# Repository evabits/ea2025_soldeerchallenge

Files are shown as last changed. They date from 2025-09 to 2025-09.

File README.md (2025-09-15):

# ea2025_soldeerchallenge

Hardware and Software for the soldering challenge of the Electronics and Automation fair 2025. The board includes an RP2040, a 5x5 neopixel LED array and a breakout connector. You can use it as an RP2040 development kit afterwards, starting with the Arduino file. Leave a note on our linkedin-page on how you've done. Good luck soldering!

## Important Notice  

Some Arduino board libraries may cause **GPIO pattern mismatches**.  

The only supported and correct board for running `FHI_SolderChallenge2025.ino` is:  

**Raspberry Pi Pico (RP2040) by Earle F. Philhower**

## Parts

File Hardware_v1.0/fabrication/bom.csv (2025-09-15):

Value | References | Footprint | Partnumber | Quantity Per PCB | Description
10pf | C6 C9 | C_0402_1005Metric |  | 2
22pF | C12 C13 | C_0402_1005Metric |  | 2
0.1uF | C1 C2 C3 C4 C5 C7 C8 | C_0402_1005Metric |  | 7
1uF | C11 C14 C15 | C_0603_1608Metric |  | 3
WS2812B | D2 D3 D4 D5 D6 D7 D8 D9 D10 D11 D12 D13 D14 D15 D16 D17 D18 D19 D20 D21 D22 D23 D24 D25 D26 | LED_WS2812B_PLCC4_5.0x5.0mm_P3.2mm |  | 25 | RGB LED with integrated controller
Conn_02x16_Odd_Even | J3 | PinHeader_2x16_P2.54mm_Horizontal |  | 1 | Generic connector, double row, 02x16, odd/even pin numbering scheme (row 1 odd numbers, row 2 even numbers), script generated (kicad-library-utils/schlib/autogen/connector/)
USB4085-GF-A_REVB | J2 | GCT_USB4085-GF-A_REVB | USB4085-GF-A | 1
27R | R8 R9 | R_0603_1608Metric |  | 2
1k5 | R1 | R_0603_1608Metric |  | 1
5k1 | R5 R6 | R_0603_1608Metric |  | 2
10K | R3 | R_0603_1608Metric |  | 1
1M | R4 | R_0603_1608Metric |  | 1
SKRKAGE020 | SW1 | SW_Push_SPST_NO_Alps_SKRK | SKRKAGE020 | 1
74HCT1G125GW | U3 | SOT-353_SC-70-5 |  | 1
AP2112K-3.3V | U4 | TSOT-23-5 |  | 1
RP2040 | U1 | QFN-56-1EP_7x7mm_P0.4mm_EP3.1x3.1mm_ThermalVias |  | 1
W25Q128JVSIQ | U2 | SOIC-8_5.23x5.23mm_P1.27mm |  | 1
EVAbits_logo | V2 | EVAbits_newlogo 48x12mm | DNP | 1
QR-code | V1 | QRcode14mmx14mm | DNP | 1
evajig_logo | V3 | evajig_logo_40x10 | DNP | 1
12MHz,10pF | Y1 | Crystal_SMD_3225-4Pin_3.2x2.5mm | NX3225SA-12MHZ-STD-CSR-6 | 1

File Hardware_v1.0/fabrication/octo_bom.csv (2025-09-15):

Num | MPN | Qty | Schematic Reference | Description
0 | 22pF capacitor 0402 50V | 2 | C12 C13 | 22pF capacitor 0402 50V
1 | WS2812B | 25 | D2 D3 D4 D5 D6 D7 D8 D9 D10 D11 D12 D13 D14 D15 D16 D17 D18 D19 D20 D21 D22 D23 D24 D25 D26
2 | Conn_02x16_Odd_Even | 1 | J3
3 | USB4085-GF-A | 1 | J2
4 | SKRKAGE020 | 1 | SW1
5 | 74HCT1G125GW | 1 | U3
6 | AP2112K-3.3V | 1 | U4
7 | RP2040 | 1 | U1
8 | W25Q128JVSIQ | 1 | U2
9 | NX3225SA-12MHZ-STD-CSR-6 | 1 | Y1

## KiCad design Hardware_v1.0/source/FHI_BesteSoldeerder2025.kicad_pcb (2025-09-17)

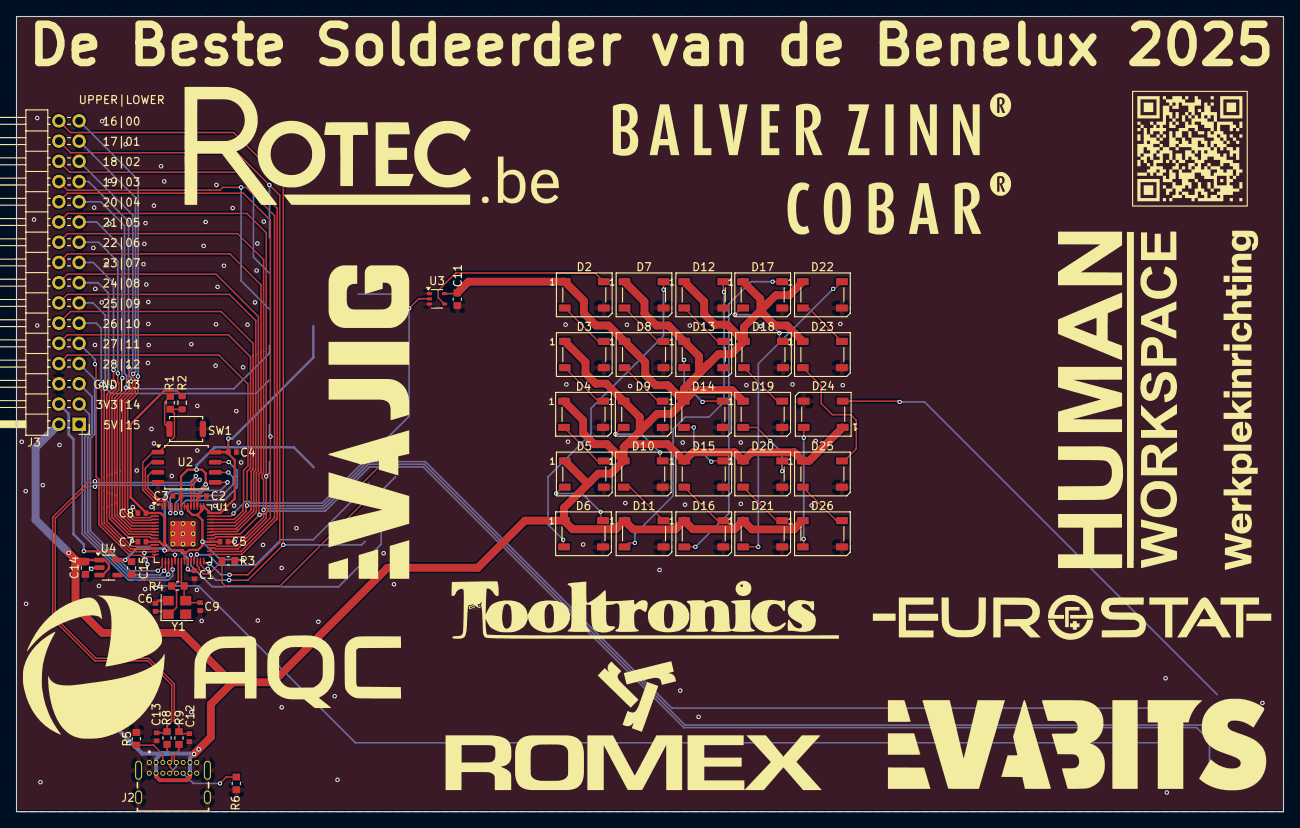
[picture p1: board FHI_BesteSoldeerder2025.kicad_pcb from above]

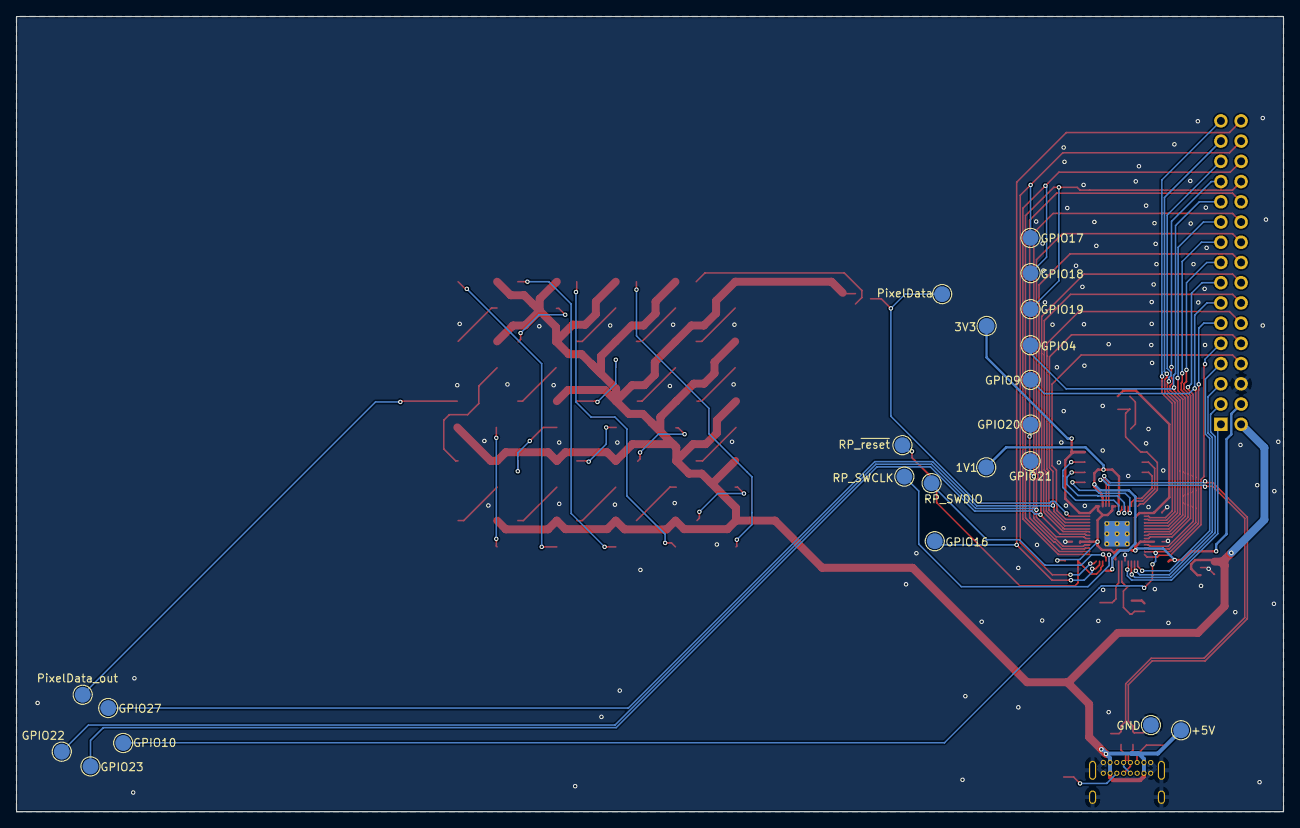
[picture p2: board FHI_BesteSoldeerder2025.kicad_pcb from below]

Board: 2 copper layers, 159.1 x 99.8 mm, 79 parts (21 on the bottom side), 78 nets.

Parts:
C1, C2, C3, C4, C5, C7, C8: 0.1uF; C_0402_1005Metric
C6, C9: 10pf; C_0402_1005Metric
C11, C14, C15: 1uF; C_0603_1608Metric
C12, C13: 22pF; C_0402_1005Metric
D2, D3, D4, D5, D6, D7, D8, D9, D10, D11, D12, D13, D14, D15, D16, D17, D18, D19, D20, D21, D22, D23, D24, D25, D26: WS2812B; LED_WS2812B_PLCC4_5.0x5.0mm_P3.2mm
J2: USB4085-GF-A_REVB; GCT_USB4085-GF-A_REVB
J3: Conn_02x16_Odd_Even; PinHeader_2x16_P2.54mm_Horizontal
R1: 1k5; R_0603_1608Metric
R2: DNP; R_0603_1608Metric
R3: 10K; R_0603_1608Metric
R4: 1M; R_0603_1608Metric
R5, R6: 5k1; R_0603_1608Metric
R8, R9: 27R; R_0603_1608Metric
SW1: SKRKAGE020; SW_Push_SPST_NO_Alps_SKRK
TP1: +5V; TestPoint_Pad_D1.5mm
TP3: GND; TestPoint_Pad_D1.5mm
TP28: GPIO27; TestPoint_Pad_D1.5mm
TP29: PixelData_out; TestPoint_Pad_D1.5mm
TP31: GPIO10; TestPoint_Pad_D1.5mm
TP32: GPIO22; TestPoint_Pad_D1.5mm
TP33: GPIO23; TestPoint_Pad_D1.5mm
TP55: GPIO21; TestPoint_Pad_D1.5mm
TP56: GPIO20; TestPoint_Pad_D1.5mm
TP57: GPIO9; TestPoint_Pad_D1.5mm
TP59: GPIO4; TestPoint_Pad_D1.5mm
TP60: GPIO19; TestPoint_Pad_D1.5mm
TP61: GPIO18; TestPoint_Pad_D1.5mm
TP62: GPIO17; TestPoint_Pad_D1.5mm
TP63: 1V1; TestPoint_Pad_D1.5mm
TP64: 3V3; TestPoint_Pad_D1.5mm
TP74: RP_SWDIO; TestPoint_Pad_D1.5mm
TP75: RP_~{reset}; TestPoint_Pad_D1.5mm
TP76: RP_SWCLK; TestPoint_Pad_D1.5mm
TP83: GPIO16; TestPoint_Pad_D1.5mm
TP84: PixelData; TestPoint_Pad_D1.5mm
U1: RP2040; QFN-56-1EP_7x7mm_P0.4mm_EP3.1x3.1mm_ThermalVias
U2: W25Q128JVSIQ; SOIC-8_5.23x5.23mm_P1.27mm
U3: 74HCT1G125GW; SOT-353_SC-70-5
U4: AP2112K-3.3V; TSOT-23-5
V1: QR-code; QRcode14mmx14mm
V2: EVAbits_logo; EVAbits_newlogo 48x12mm
V3: evajig_logo; evajig_logo_40x10
Y1: 12MHz,10pF; Crystal_SMD_3225-4Pin_3.2x2.5mm

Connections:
+3V3: C4.2, C5.2, C7.2, C8.2, C15.2, J3.4, R2.1, R3.2, TP64.1, U1.1 (IOVDD), U1.10 (IOVDD), U1.22 (IOVDD), U1.33 (IOVDD), U1.42 (IOVDD), U1.43 (ADC-AVDD), U1.44 (VREG-VIN), U1.48 (USB-VDD), U1.49 (IOVDD), U2.8 (VCC), U4.5 (OUT)
+5V: C11.2, C14.2, D2.1 (VDD), D3.1 (VDD), D4.1 (VDD), D5.1 (VDD), D6.1 (VDD), D7.1 (VDD), D8.1 (VDD), D9.1 (VDD), D10.1 (VDD), D11.1 (VDD), D12.1 (VDD), D13.1 (VDD), D14.1 (VDD), D15.1 (VDD), D16.1 (VDD), D17.1 (VDD), D18.1 (VDD), D19.1 (VDD), D20.1 (VDD), D21.1 (VDD), D22.1 (VDD), D23.1 (VDD), D24.1 (VDD), D25.1 (VDD), D26.1 (VDD), J2.A4 (VBUS), J2.A9 (VBUS), J2.B4 (VBUS), J2.B9 (VBUS), J3.2, TP1.1, U3.5 (Vcc), U4.1 (IN), U4.3 (EN)
/+1v1: C1.2, C2.2, C3.2, TP63.1, U1.23 (DVDD), U1.45 (VREG-VOUT), U1.50 (DVDD)
/GPIO00: J3.31, U1.2 (GPIO0)
/GPIO01: J3.29, U1.3 (GPIO1)
/GPIO02: J3.27, U1.4 (GPIO2)
/GPIO03: J3.25, U1.5 (GPIO3)
/GPIO04: J3.23, TP59.1, U1.6 (GPIO4)
/GPIO05: J3.21, U1.7 (GPIO5)
/GPIO06: J3.19, U1.8 (GPIO6)
/GPIO07: J3.17, U1.9 (GPIO7)
/GPIO08: J3.15, U1.11 (GPIO8)
/GPIO09: J3.13, TP57.1, U1.12 (GPIO9)
/GPIO10: J3.11, TP31.1, U1.13 (GPIO10)
/GPIO11: J3.9, U1.14 (GPIO11)
/GPIO12: J3.7, U1.15 (GPIO12)
/GPIO13: J3.5, U1.16 (GPIO13)
/GPIO14: J3.3, U1.17 (GPIO14)
/GPIO15: J3.1, U1.18 (GPIO15)
/GPIO16: J3.32, TP83.1, U1.27 (GPIO16)
/GPIO17: J3.30, TP62.1, U1.28 (GPIO17)
/GPIO18: J3.28, TP61.1, U1.29 (GPIO18)
/GPIO19: J3.26, TP60.1, U1.30 (GPIO19)
/GPIO20: J3.24, TP56.1, U1.31 (GPIO20)
/GPIO21: J3.22, TP55.1, U1.32 (GPIO21)
/GPIO22: J3.20, TP32.1, U1.34 (GPIO22)
/GPIO23: J3.18, TP33.1, U1.35 (GPIO23)
/GPIO24: J3.16, U1.36 (GPIO24)
/GPIO25: J3.14, U1.37 (GPIO25)
/GPIO26: J3.12, U1.38 (GPIO26/ADC0)
/GPIO27: J3.10, TP28.1, U1.39 (GPIO27/ADC1)
/GPIO28: J3.8, U1.40 (GPIO28/ADC2)
/NeoPixel_data: TP84.1, U1.41 (GPIO29/ADC3), U3.2 (A)
/NeoPixel_data_out: D24.2 (DOUT), TP29.1
/PICO_RESET: R3.1, TP75.1, U1.26 (RUN)
/PICO_TCKS: TP76.1, U1.24 (SWCLK)
/PICO_TMSS: TP74.1, U1.25 (SWDIO)
/QSPI_SCLK: U1.52 (QSPI-SCLK), U2.6 (CLK)
/QSPI_SD0: U1.53 (QSPI-SD0), U2.5 (DI(IO0))
/QSPI_SD1: U1.55 (QSPI-SD1), U2.2 (DO(IO1))
/QSPI_SD2: U1.54 (QSPI-SD2), U2.3 (IO2)
/QSPI_SD3: U1.51 (QSPI-SD3), U2.7 (IO3)
/QSPI_SS: R1.2, R2.2, U1.56 (QSPI-SS-N), U2.1 (~CS)
/USB_D+: C13.2, R8.1, U1.47 (USB-DP)
/USB_D-: C12.1, R9.1, U1.46 (USB-DM)
/USB_N: J2.A7 (DN1), J2.B7 (DN2), R9.2
/USB_P: J2.A6 (DP1), J2.B6 (DP2), R8.2
/~USB_BOOT: R1.1, SW1.2
GND: C1.1, C2.1, C3.1, C4.1, C5.1, C6.2, C7.1, C8.1, C9.1, C11.1, C12.2, C13.1, C14.1, C15.1, D2.3 (VSS), D3.3 (VSS), D4.3 (VSS), D5.3 (VSS), D6.3 (VSS), D7.3 (VSS), D8.3 (VSS), D9.3 (VSS), D10.3 (VSS), D11.3 (VSS), D12.3 (VSS), D13.3 (VSS), D14.3 (VSS), D15.3 (VSS), D16.3 (VSS), D17.3 (VSS), D18.3 (VSS), D19.3 (VSS), D20.3 (VSS), D21.3 (VSS), D22.3 (VSS), D23.3 (VSS), D24.3 (VSS), D25.3 (VSS), D26.3 (VSS), J2.A1 (GND), J2.A12 (GND), J2.B1 (GND), J2.B12 (GND), J2.S1 (SHELL), J2.S2 (SHELL), J2.S3 (SHELL), J2.S4 (SHELL), J3.6, R5.2, R6.2, SW1.1, TP3.1, U1.19 (TESTEN), U1.57 (GND), U2.4 (GND), U3.1 (~OE), U3.3 (GND), U4.2 (GND), Y1.2, Y1.4
unnamed: D2.4 (DIN), U3.4 (Y)
unnamed: D2.2 (DOUT), D3.4 (DIN)
unnamed: D3.2 (DOUT), D4.4 (DIN)
unnamed: D4.2 (DOUT), D5.4 (DIN)
unnamed: D5.2 (DOUT), D6.4 (DIN)
unnamed: D6.2 (DOUT), D7.4 (DIN)
unnamed: D7.2 (DOUT), D8.4 (DIN)
unnamed: D8.2 (DOUT), D9.4 (DIN)
unnamed: D9.2 (DOUT), D10.4 (DIN)
unnamed: D10.2 (DOUT), D11.4 (DIN)
unnamed: D11.2 (DOUT), D12.4 (DIN)
unnamed: D12.2 (DOUT), D13.4 (DIN)
unnamed: D13.2 (DOUT), D14.4 (DIN)
unnamed: D14.2 (DOUT), D15.4 (DIN)
unnamed: D15.2 (DOUT), D16.4 (DIN)
unnamed: D16.2 (DOUT), D17.4 (DIN)
unnamed: D17.2 (DOUT), D18.4 (DIN)
unnamed: D18.2 (DOUT), D19.4 (DIN)
unnamed: D19.2 (DOUT), D20.4 (DIN)
unnamed: D20.2 (DOUT), D21.4 (DIN)
unnamed: D21.2 (DOUT), D22.4 (DIN)
unnamed: D22.2 (DOUT), D23.4 (DIN)
unnamed: D23.2 (DOUT), D25.4 (DIN)
unnamed: D24.4 (DIN), D26.2 (DOUT)
unnamed: D25.2 (DOUT), D26.4 (DIN)
unnamed: J2.A5 (CC1), R5.1
unnamed: J2.B5 (CC2), R6.1
unnamed: C6.1, R4.2, U1.20 (XIN), Y1.1
unnamed: C9.2, R4.1, U1.21 (XOUT), Y1.3

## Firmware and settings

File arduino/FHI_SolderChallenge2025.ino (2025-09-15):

/// @file    Blink.ino
/// @brief   Blink the first LED of an LED strip
/// @example Blink.ino

// install the library to use FastLED.h
// https://docs.arduino.cc/libraries/fastled/
#include <FastLED.h>

// How many leds in your strip?
#define NUM_LEDS 25

#define LETTER_SPACING 0

#define NUM_PINS 28
// For led chips like WS2812, which have a data line, ground, and power, you just
// need to define DATA_PIN.  For led chipsets that are SPI based (four wires - data, clock,
// ground, and power), like the LPD8806 define both DATA_PIN and CLOCK_PIN
// Clock pin only needed for SPI based chipsets when not using hardware SPI
#define DATA_PIN 29
#define CLOCK_PIN 13

// Define the array of leds
CRGB leds[NUM_LEDS];

// Checkmark pattern
int checkmark[] = { 3, 9, 13, 17, 21 };
int checkmarkSize = sizeof(checkmark) / sizeof(checkmark[0]);

// Cross pattern
int cross[] = { 0, 6, 12, 18, 23, 20, 16, 8, 4 };
int crossSize = sizeof(cross) / sizeof(cross[0]);

// Pointer to faulty led
int pointer[] = { 2, 7, 12, 17, 11, 13 };
int pointerSize = sizeof(pointer) / sizeof(pointer[0]);

// Snake sequence
int snakeOrder[] = { 0, 5, 10, 15, 20, 21, 16, 11, 6, 1, 2, 7, 12, 17, 24, 22, 18, 13, 8, 3, 4, 9, 14, 19, 23 };
int snakeSize = sizeof(snakeOrder) / sizeof(snakeOrder[0]);

#define NUM_ROWS 5
#define NUM_COLS 5


// Array for each symbol  
const byte FONT_5x5[][NUM_ROWS] = {

  /* 'P' */ {
    0b11100,
    0b10010,
    0b11100,
    0b10000,
    0b10000
    },

  /* 'A' */ {
    0b01000,
    0b10100,
    0b11100,
    0b10100,
    0b10100
    },

  /* 'S' */ {
    0b01100,
    0b10000,
    0b01000,
    0b00100,
    0b11000},

  /* ! */ {
    0b10000,
    0b10000,
    0b10000,
    0b00000,
    0b10000
    }, 

  /* 'F' */ {
    0b11100,
    0b10000,
    0b11000,
    0b10000,
    0b10000
    },

  /* I */ {
    0b11100,
    0b01000,
    0b01000,
    0b01000,
    0b11100
    }, 

  /* L */ {
    0b10000,
    0b10000,
    0b10000,
    0b10000,
    0b11110
    }, 

  /* ' ' */ {
    0b00000,
    0b00000,
    0b00000,
    0b00000,
    0b00000
    }, // space
};

 
// LED map for letter scrolling
const uint8_t LED_MAP[NUM_ROWS][NUM_COLS] = {
  { 0,  5, 10, 15, 20 },
  { 1,  6, 11, 16, 21 },
  { 2,  7, 12, 17, 24 },
  { 3,  8, 13, 18, 22 },
  { 4,  9, 14, 19, 23 }
};

// store patterns
int fontIndexFromChar(char c) {
  switch (c) {
    case 'P': return 0;
    case 'A': return 1;
    case 'S': return 2;
    case '!': return 3;
    case 'F': return 4;
    case 'I': return 5;
    case 'L': return 6;
    case ' ': return 7;
    default:  return 7; // unknown -> space
  }
}

// matrix coordinates
inline int indexFromRowCol(int row, int col) {
  return LED_MAP[row][col];
}


//GPIO pins
int gpioPins[29] = {
  0, 1, 2, 3, 4, 5, 6, 7,
  8, 9, 10, 11, 12, 13, 14, 15,
  16, 17, 18, 19, 20, 21, 22, 23,
  24, 25, 26, 27, 28
};



// draw a single character column-by-column onto the 5x5 at a given global column
void drawTextColumnAt(int visCol, int globalCol, const char* text, CRGB color) {
  if (visCol < 0 || visCol >= NUM_COLS) return;

  // each character is NUM_COLS wide + 1 blank column spacing
  const int charWidth = NUM_COLS;
  const int spacing   = LETTER_SPACING;
  const int stride    = charWidth + spacing;

  if (globalCol < 0) return;

  // which character & which column inside that character?
  int charIdx     = globalCol / stride;
  int colInChar   = globalCol % stride;

  // outside the input string?
  int textLen = strlen(text);
  if (charIdx >= textLen) return;

  // spacing column?
  if (colInChar >= charWidth) return;

  // fetch the character's 5 row bitmap
  char c = toupper(text[charIdx]);
  int fi = fontIndexFromChar(c);

  // Copy pixels for this visible column
  for (int row = 0; row < NUM_ROWS; row++) {
    bool on = ((FONT_5x5[fi][row] >> (NUM_COLS - 1 - colInChar)) & 0x01);
     int idx = indexFromRowCol(row, visCol);
    if (idx >= 0 && idx < NUM_LEDS) {
      leds[idx] = on ? color : CRGB::Black;
    }
  }
}

// scroll the text 
void scrollText(const char* text, uint16_t stepDelayMs, CRGB color) {
  // total columns in the virtual text
  const int charWidth = NUM_COLS;
  const int spacing   = LETTER_SPACING;
  const int stride    = charWidth + spacing;
  int textCols = strlen(text) * stride;

  // sweep from off-screen right to off-screen left
  for (int offset = NUM_COLS; offset >= -textCols; offset--) {
    // Clear frame
    for (int i = 0; i < NUM_LEDS; i++) leds[i] = CRGB::Black;

    // render visible window columns
    for (int visCol = 0; visCol < NUM_COLS; visCol++) {
      int globalCol = visCol - offset; // which text column appears in this window column?
      drawTextColumnAt(visCol, globalCol, text, color);
    }

    FastLED.show();
    delay(stepDelayMs);
  }
}


void setup() {
  Serial.begin(115200);

  // Initialize pins
  for (int i = 0; i < 28; i++) {
    pinMode(gpioPins[i], OUTPUT);
  }

  // Uncomment/edit one of the following lines for your leds arrangement.
  // ## Clockless types ##
  FastLED.addLeds<NEOPIXEL, DATA_PIN>(leds, NUM_LEDS);  // GRB ordering is assumed

  

  // FastLED.addLeds<SM16703, DATA_PIN, RGB>(leds, NUM_LEDS);
  // FastLED.addLeds<TM1829, DATA_PIN, RGB>(leds, NUM_LEDS);
  // FastLED.addLeds<TM1812, DATA_PIN, RGB>(leds, NUM_LEDS);
  // FastLED.addLeds<TM1809, DATA_PIN, RGB>(leds, NUM_LEDS);
  // FastLED.addLeds<TM1804, DATA_PIN, RGB>(leds, NUM_LEDS);
  // FastLED.addLeds<TM1803, DATA_PIN, RGB>(leds, NUM_LEDS);
  // FastLED.addLeds<UCS1903, DATA_PIN, RGB>(leds, NUM_LEDS);
  // FastLED.addLeds<UCS1903B, DATA_PIN, RGB>(leds, NUM_LEDS);
  // FastLED.addLeds<UCS1904, DATA_PIN, RGB>(leds, NUM_LEDS);
  // FastLED.addLeds<UCS2903, DATA_PIN, RGB>(leds, NUM_LEDS);
  // FastLED.addLeds<WS2812, DATA_PIN, RGB>(leds, NUM_LEDS);  // GRB ordering is typical
  // FastLED.addLeds<WS2852, DATA_PIN, RGB>(leds, NUM_LEDS);  // GRB ordering is typical
  // FastLED.addLeds<WS2812B, DATA_PIN, RGB>(leds, NUM_LEDS);  // GRB ordering is typical
  // FastLED.addLeds<GS1903, DATA_PIN, RGB>(leds, NUM_LEDS);
  // FastLED.addLeds<SK6812, DATA_PIN, RGB>(leds, NUM_LEDS);  // GRB ordering is typical
  // FastLED.addLeds<SK6822, DATA_PIN, RGB>(leds, NUM_LEDS);
  // FastLED.addLeds<APA106, DATA_PIN, RGB>(leds, NUM_LEDS);
  // FastLED.addLeds<PL9823, DATA_PIN, RGB>(leds, NUM_LEDS);
  // FastLED.addLeds<SK6822, DATA_PIN, RGB>(leds, NUM_LEDS);
  // FastLED.addLeds<WS2811, DATA_PIN, RGB>(leds, NUM_LEDS);
  // FastLED.addLeds<WS2813, DATA_PIN, RGB>(leds, NUM_LEDS);
  // FastLED.addLeds<APA104, DATA_PIN, RGB>(leds, NUM_LEDS);
  // FastLED.addLeds<WS2811_400, DATA_PIN, RGB>(leds, NUM_LEDS);
  // FastLED.addLeds<GE8822, DATA_PIN, RGB>(leds, NUM_LEDS);
  // FastLED.addLeds<GW6205, DATA_PIN, RGB>(leds, NUM_LEDS);
  // FastLED.addLeds<GW6205_400, DATA_PIN, RGB>(leds, NUM_LEDS);
  // FastLED.addLeds<LPD1886, DATA_PIN, RGB>(leds, NUM_LEDS);
  // FastLED.addLeds<LPD1886_8BIT, DATA_PIN, RGB>(leds, NUM_LEDS);
  // ## Clocked (SPI) types ##
  // FastLED.addLeds<LPD6803, DATA_PIN, CLOCK_PIN, RGB>(leds, NUM_LEDS);  // GRB ordering is typical
  // FastLED.addLeds<LPD8806, DATA_PIN, CLOCK_PIN, RGB>(leds, NUM_LEDS);  // GRB ordering is typical
  // FastLED.addLeds<WS2801, DATA_PIN, CLOCK_PIN, RGB>(leds, NUM_LEDS);
  // FastLED.addLeds<WS2803, DATA_PIN, CLOCK_PIN, RGB>(leds, NUM_LEDS);
  // FastLED.addLeds<SM16716, DATA_PIN, CLOCK_PIN, RGB>(leds, NUM_LEDS);
  // FastLED.addLeds<P9813, DATA_PIN, CLOCK_PIN, RGB>(leds, NUM_LEDS);  // BGR ordering is typical
  // FastLED.addLeds<DOTSTAR, DATA_PIN, CLOCK_PIN, RGB>(leds, NUM_LEDS);  // BGR ordering is typical
  // FastLED.addLeds<APA102, DATA_PIN, CLOCK_PIN, RGB>(leds, NUM_LEDS);  // BGR ordering is typical
  // FastLED.addLeds<SK9822, DATA_PIN, CLOCK_PIN, RGB>(leds, NUM_LEDS);  // BGR ordering is typical
  FastLED.setBrightness(3);

  // for (int dot = 0; dot < NUM_LEDS; dot++) {

  //   for (int Hue = 0; Hue < 255; dot++) {
  //     Hue = Hue + 10;
  //     if (Hue == 0) {
  //       Hue = 10;
  //     }
  //     leds[dot] = CHSV(Hue, 255, 255);
  //     FastLED.show();
  //   }
  // }

  Serial.println("Ready: Type commands (p1, p2, ok, cross)");
}




void loop() {

  // leds[25] = leds[0];

  // for(int i = 0; i < 25 ; i++){
  //   leds[i] = leds[i+1];
  //   delay(3);
  // }
  //   FastLED.show();

  // Blink the last LED (faulty one)
  // leds[24] = CRGB::Red;
  // FastLED.show();
  // delay(500);
  // leds[24] = CRGB::Black;
  // FastLED.show();
  // delay(500);


  // // Parse all LEDs
  // for (int i=0; i<25; i++){
  // // Turn the LED on, then pause
  // leds[i] = CRGB::Red;
  // FastLED.show();
  // delay(100);
  // // Now turn the LED off, then pause
  // leds[i] = CRGB::Black;
  // FastLED.show();
  // delay(100);
  // }

  if (Serial.available()) {
    String command = Serial.readStringUntil('\n');  // Read command from PuTTY
    command.trim();                                 // Remove spaces/newlines
    // type the commands to activate functions
    if (command == "p1") {
      Serial.println("pattern 1 selected");
      pattern1();
    } else if (command == "p2") {
      Serial.println("pattern 2 selected");
      pattern2();
    } else if (command == "p3") {
      Serial.println("show the faulty LED");
      ledParse();
    } else if (command == "s") {
      Serial.println("show snake animation");
      snakePattern();
    } else if (command == "ok") {
      Serial.println("show checkmark");
      showCheckmark();
    } else if (command == "cross") {
      Serial.println("show cross");
      showCross();
    }else if (command == "pass") {
      Serial.println("scroll P");
      scrollText("PASS!",210, CRGB::Green); 
    }
    else if (command == "fail") {
    Serial.println("scroll FAIL");
    scrollText("FAIL!", 210, CRGB::Red);
    } else {
      Serial.println("Unknown command");
    }
  }

  // ledParse();
  // delay(2000);

  // showPointer();
  // delay(1000);


  // showCheckmark();
  // delay(1000);

  // showCross();
  // delay(1000);

}



void pattern1() {

  for (int i = 0; i < 22; i++) {  // Stop before 22 to handle 22,23,24 separately
    if (i % 2 == 0) {
      leds[i] = CRGB::Green;  // Even index ON
    } else {
      leds[i] = CRGB::Black;  // Odd index OFF
    }
  }

  // Handle these seperately
  leds[22] = CRGB::Black;
  leds[23] = CRGB::Green;
  leds[24] = CRGB::Green;

  FastLED.show();

  // GPIO pattern, enable only odd numbers
  for (int i = 0; i <= NUM_PINS; i++) {
    if (i % 2 == 0) {
      digitalWrite(gpioPins[i], LOW);
      Serial.print("GPIO");
      Serial.print(gpioPins[i]);
      Serial.println(" = LOW");
    } else {
      digitalWrite(gpioPins[i], HIGH);
      Serial.print("GPIO");
      Serial.print(gpioPins[i]);
      Serial.println(" = HIGH");
    }
  }

  



  delay(3000);

  // Turn everything OFF
  for (int i = 0; i < 25; i++) {
    leds[i] = CRGB::Black;
  }
  FastLED.show();

  // Set all pins LOW
  for (int i = 0; i <= NUM_PINS; i++) {
    digitalWrite(gpioPins[i], LOW);
  }
  Serial.println("All pins LOW now");

}

void pattern2() {

  for (int i = 0; i < 22; i++) {  // Stop before 22 to handle 22,23,24 separately
    if (i % 2 == 0) {
      leds[i] = CRGB::Black;  // Even index OFF
    } else {
      leds[i] = CRGB::Green;  // Odd index ON
    }
  }

  leds[22] = CRGB::Green;
  leds[23] = CRGB::Black;
  leds[24] = CRGB::Black;

  FastLED.show();
  
  // Inverted GPIO pattern, enable only even numbers
  for (int i = 0; i <= NUM_PINS; i++) {
    if (i % 2 == 0) {
      digitalWrite(gpioPins[i], HIGH);
      Serial.print("GPIO");
      Serial.print(gpioPins[i]);
      Serial.println(" = HIGH");
    } else {
      digitalWrite(gpioPins[i], LOW);
      Serial.print("GPIO");
      Serial.print(gpioPins[i]);
      Serial.println(" = LOW");
    }
  }

  delay(3000);

  // Turn everything OFF
  for (int i = 0; i < 25; i++) {
    leds[i] = CRGB::Black;
  }
  FastLED.show();

   // Set all pins LOW
  for (int i = 0; i <= NUM_PINS; i++) {
    digitalWrite(gpioPins[i], LOW);
  }
  Serial.println("All pins LOW now");
}


void showPointer() {
  for (int i = 0; i < pointerSize; i++) {
    leds[pointer[i]] = CRGB::Green;
  }
  //Blink the last LED (faulty one)
  leds[24] = CRGB::Red;

  FastLED.show();
  delay(2000);

  // Turn them off
  for (int i = 0; i < pointerSize; i++) {
    leds[pointer[i]] = CRGB::Black;
  }
  leds[24] = CRGB::Black;

  FastLED.show();
}

void ledParse() {
  //Parse all LEDs
  for (int i = 0; i < 24; i++) {
    // Turn the LED on, then pause
    leds[i] = CRGB::Green;
    FastLED.show();
    delay(100);
    // Now turn the LED off, then pause
    leds[i] = CRGB::Black;
    FastLED.show();
    delay(100);

    if (i == 21) {
      leds[24] = CRGB::Green;
      FastLED.show();
      delay(100);
      // Now turn the LED off, then pause
      leds[24] = CRGB::Black;
      FastLED.show();
      delay(100);
    }
  }

  // Turn on all LEDs except D24
  for (int i = 0; i < NUM_LEDS; i++) {
    if (i == 24) continue;
    leds[i] = CRGB::Green;
  }
  leds[24] = CRGB::Red;
  FastLED.show();
  delay(2000);

  // Turn all LEDs off
  for (int i = 0; i < NUM_LEDS; i++) {
    leds[i] = CRGB::Black;
  }
  FastLED.show();
  delay(1000);
}

void showCheckmark() {
  //Turn on LEDs for the checkmark one by one
  for (int i = 0; i < checkmarkSize; i++) {
    leds[checkmark[i]] = CRGB::Green;
    FastLED.show();
    delay(100);
  }

  FastLED.show();
  delay(2000);

  // Turn them off
  for (int i = 0; i < checkmarkSize; i++) {
    leds[checkmark[i]] = CRGB::Black;
  }
  FastLED.show();
}

void showCross() {
  // Turn on LEDs for the cross in one by one
  for (int i = 0; i < crossSize; i++) {
    leds[cross[i]] = CRGB::Red;
    FastLED.show();
    delay(100);
  }
  FastLED.show();
  delay(2000);

  // Turn them off
  for (int i = 0; i < crossSize; i++) {
    leds[cross[i]] = CRGB::Black;
  }
  FastLED.show();
}

void snakePattern() {
  for (int i = 0; i < snakeSize; i++) {
    leds[snakeOrder[i]] = CRGB::Orange;  // Turn ON current LED
    FastLED.show();
    delay(150);

    // Optional: turn OFF previous LED for moving dot effect
    if (i > 0) {
      leds[snakeOrder[i - 1]] = CRGB::Black;
    }
  }

  // Turn off last LED
  leds[snakeOrder[snakeSize - 1]] = CRGB::Black;
  FastLED.show();
  delay(500);
}

/*
  // Turn the LED on, then pause
  leds[4] = CRGB::Red;
  FastLED.show();
  delay(500);
  // Now turn the LED off, then pause
  leds[4] = CRGB::Black;
  FastLED.show();
  delay(500);

*/

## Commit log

2025-09-15 for public
    [FHI_BesteSoldeerder2025.kicad_pcb, FHI_BesteSoldeerder2025.kicad_sch, FHI_BesteSoldeerder2025_panel.kicad_pcb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]
2025-09-16 removed unused BoMlines, updated iBOM
    [FHI_BesteSoldeerder2025.kicad_pcb]
2025-09-17 removed more useless BoMlines, updated iBOM
    [FHI_BesteSoldeerder2025.kicad_pcb]

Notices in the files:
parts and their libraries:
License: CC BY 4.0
